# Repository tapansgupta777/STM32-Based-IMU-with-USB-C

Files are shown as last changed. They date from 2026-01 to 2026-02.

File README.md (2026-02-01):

# STM32-Based Inertial Measurement Unit (IMU) Module with USB-C

## 1. Project Overview

> NOTE :
> This project is a result of independent, self-directed study into professional PCB and circuit design. 
> I have implemented an industry-standard design flow modeled after professional methodologies
> . As this is a learning-focused implementation, 
> certain oversights or errors may exist. I highly value constructive feedback, 
> technical suggestions, or design recommendations to further my growth in this field.

This project presents a **custom STM32-based inertial measurement unit (IMU) module** built around the **STM32F411CEU6** microcontroller and the **MPU-6050** six-axis motion sensor. The board is designed as a compact embedded platform for motion sensing, orientation tracking, and IMU data acquisition.

A **USB Type-C interface** is used for both **power delivery and data communication**, allowing IMU data to be transferred directly to a host system while providing a robust and reversible physical connector. The design integrates USB protection circuitry and a regulated power architecture suitable for reliable embedded operation.

The complete schematic and PCB layout were developed in **Altium Designer**, following established industry practices for power integrity, grounding, and multilayer PCB design.

---

## 2. System Workflow

The following diagram illustrates the high-level operational workflow of the STM32-based IMU module, including power delivery, motion sensing, data processing, and host communication.

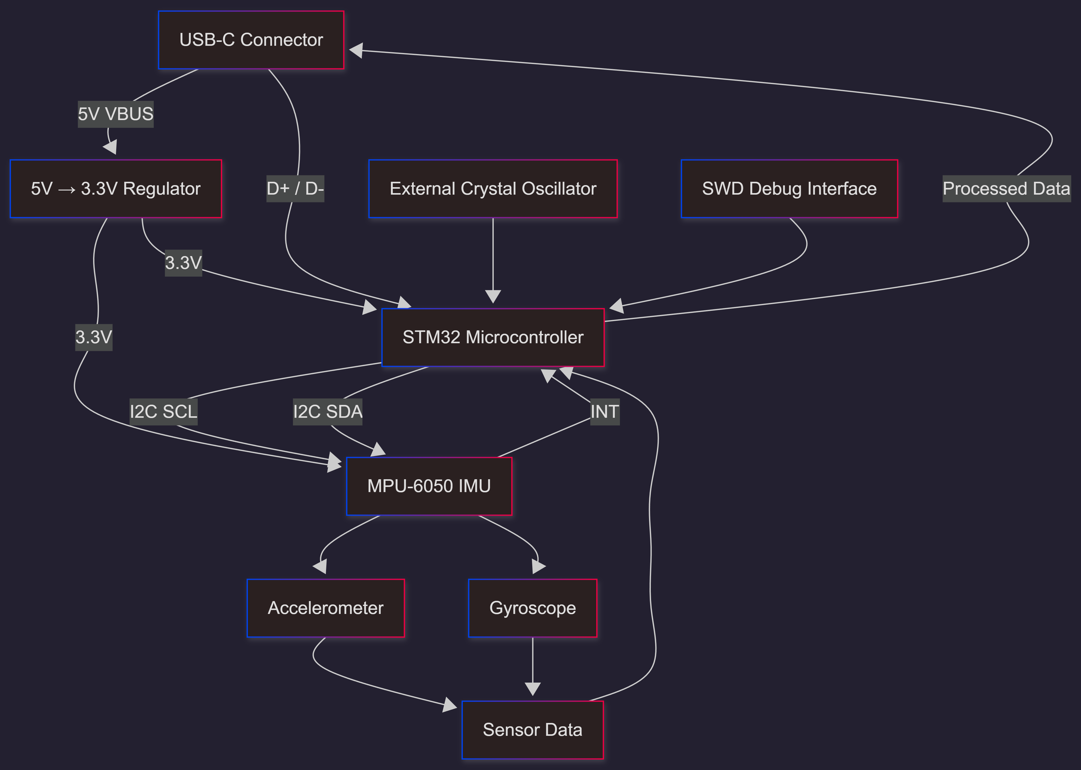
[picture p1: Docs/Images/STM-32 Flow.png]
System Workflow Diagram


---

## 3. System Architecture

At a system level, the module consists of four primary functional blocks:

- USB-C interface for power and USB 2.0 data
- Power regulation subsystem generating a stable 3.3 V rail
- STM32F411 microcontroller for control and processing
- MPU-6050 IMU for motion sensing

The STM32 acts as the central controller, acquiring motion data from the IMU over I²C, processing it in firmware, and transmitting it to an external host via USB.

### Hardware Architecture Summary

| Summary | Schematic |
| --- | --- |
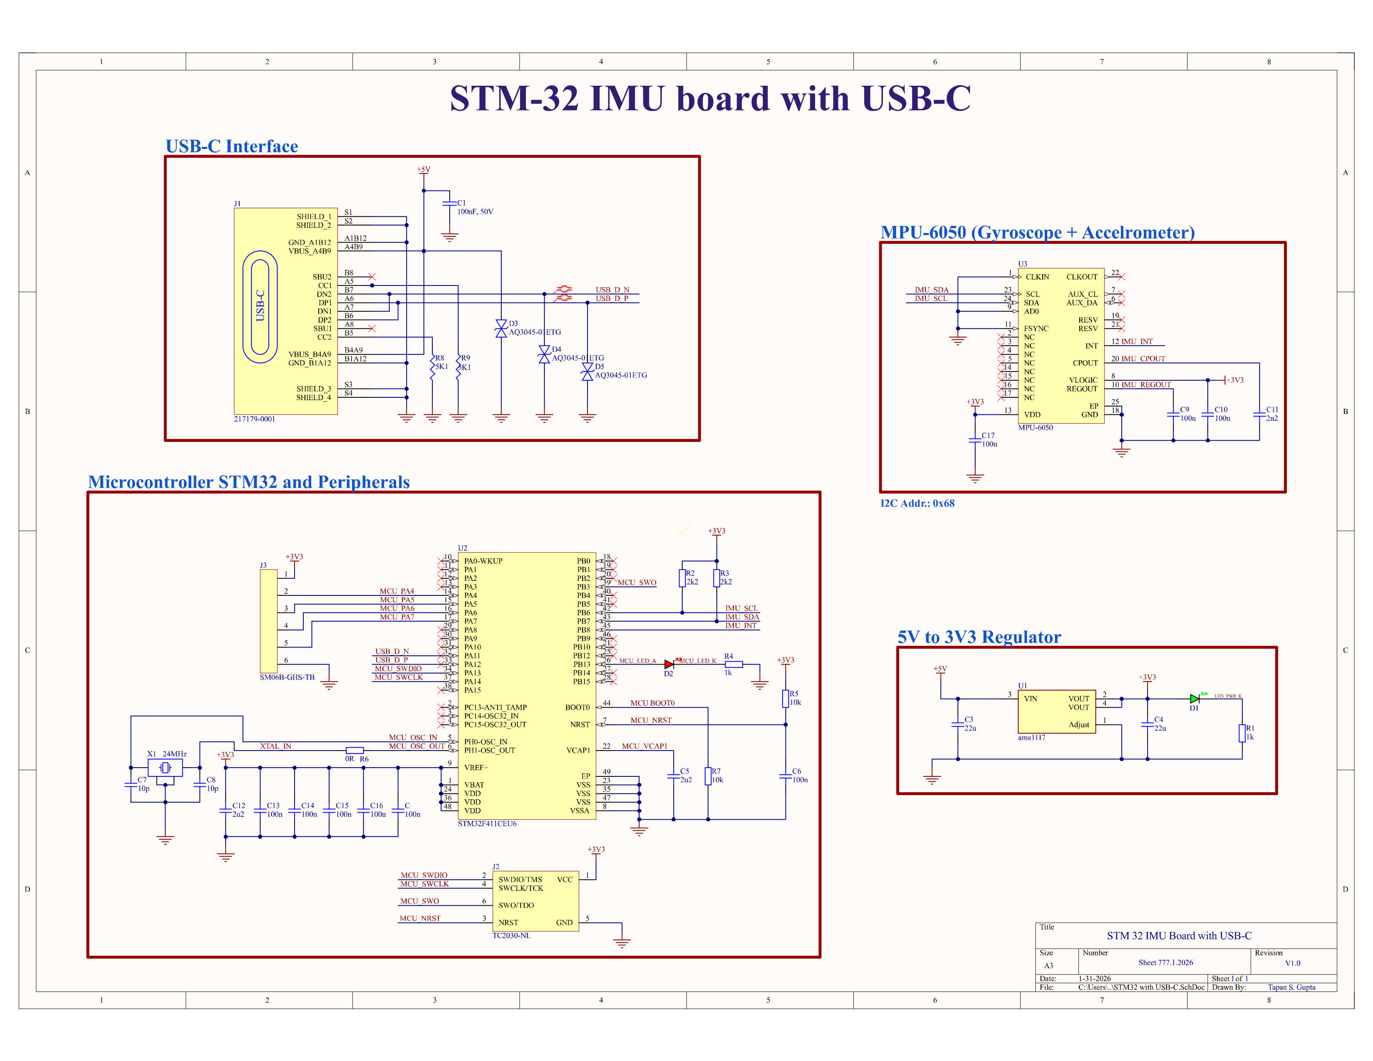
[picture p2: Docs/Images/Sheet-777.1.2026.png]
Design
| • **MCU:** `STM32F411CEU6 with 24MHz external crystal and SWD via Tag-Connect.` <br> • **Sensor:** `MPU-6050 6-axis IMU via I2C (PB8/PB9).` <br> • **USB-C:** `With ESD protection and 5.1kΩ CC pull-downs.` <br> • **Power:** `AMS1117-3.3V LDO converts 5V VBUS to 3.3V.` <br> • **I2C Addr:** `0x68 (AD0 to GND).` <br> • **Interrupts:** `IMU_INT on PB12.` <br> • **Indicators:** `Power LED + Status LED (PB13).` <br> • **Decoupling:** `100nF/2.2µF filter network.` <br> • **Routing:** `USB 90Ω differential impedance.` <br> • **IO Layout:** `Compact 6-pin header.` |  |

---

## 4. Hardware Design

### 4.1 MCU Subsystem

The microcontroller subsystem is based on the **STM32F411CEU6**, an ARM Cortex-M4 device with floating-point support.

Key design aspects include:
- External **24 MHz crystal oscillator** for accurate system timing
- SWD interface for programming and debugging
- Dedicated decoupling capacitors placed close to VDD pins
- Clean ground reference through continuous internal ground planes

The MCU is configured as a USB device and manages sensor communication, data handling, and host interaction.

---

### 4.2 IMU Subsystem

The motion sensing subsystem uses the **MPU-6050**, providing:
- 3-axis accelerometer
- 3-axis gyroscope

Design characteristics:
- Communication via I²C bus
- On-board I²C pull-up resistors
- IMU interrupt pin routed to the STM32 for event-driven data handling
- Placement optimized to reduce noise coupling from power and USB traces

The interrupt line enables efficient motion data acquisition without constant polling.

---

### 4.3 Power & USB-C Subsystem

Power is supplied through a **USB Type-C connector (217179-0001)** configured for USB 2.0 operation.

Key elements:
- 5 V input from USB-C
- **AMS1117 LDO** regulating 5 V down to 3.3 V
- USB ESD protection using **AQ3045-01ETG** diodes
- Common 3.3 V rail shared by MCU and IMU

The USB-C port supports both power input and data transfer, enabling a single-cable interface for development and data logging.

---

## 5. PCB Stackup & Layout

The PCB uses a **4-layer stackup** to improve signal integrity and reduce noise.

- Dedicated internal ground planes provide a low-impedance return path
- Extensive ground stitching vias are used to minimize EMI
- Sensitive IMU signals are routed away from high-speed USB traces

Board dimensions: **36 cm × 36 cm**

<p float="centre">
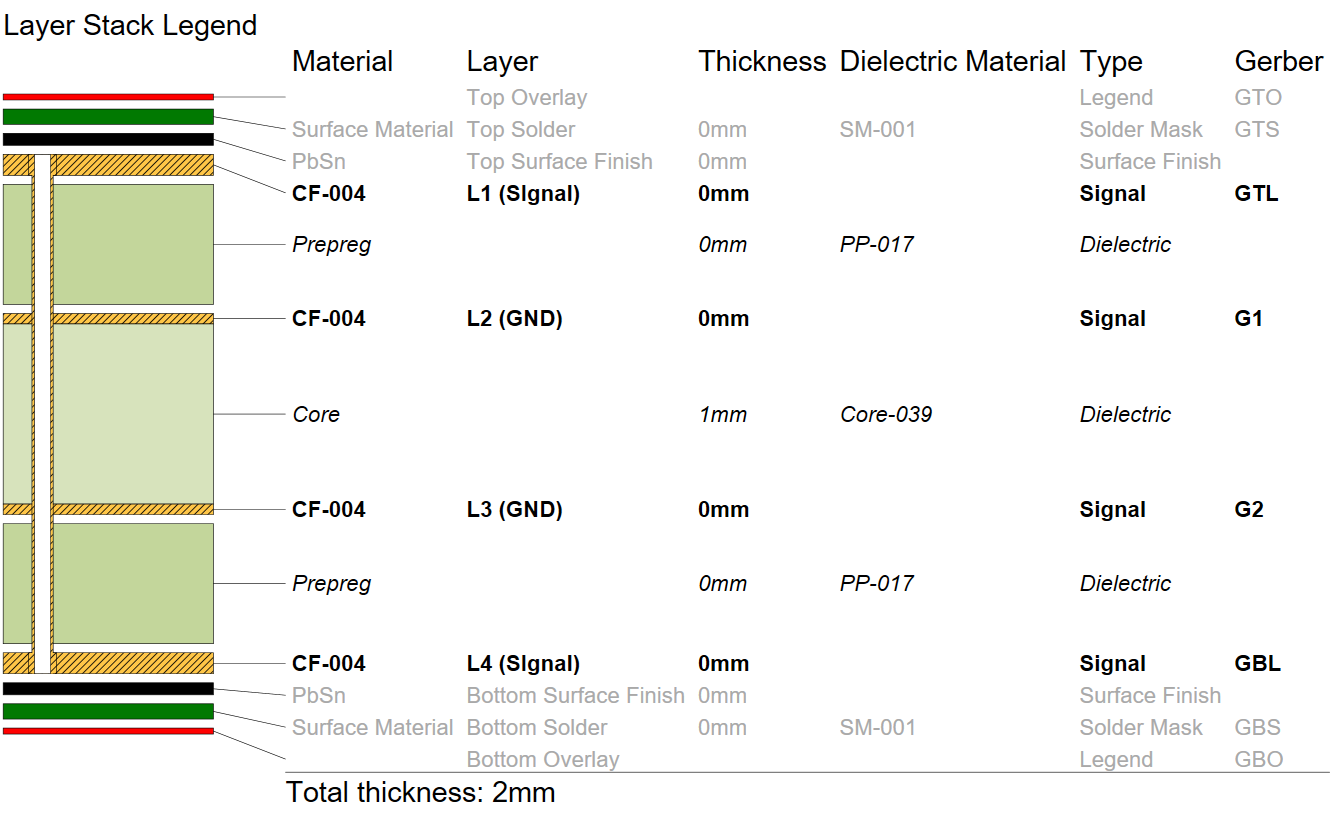
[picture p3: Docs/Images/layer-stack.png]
  
</p>

<p float="left">
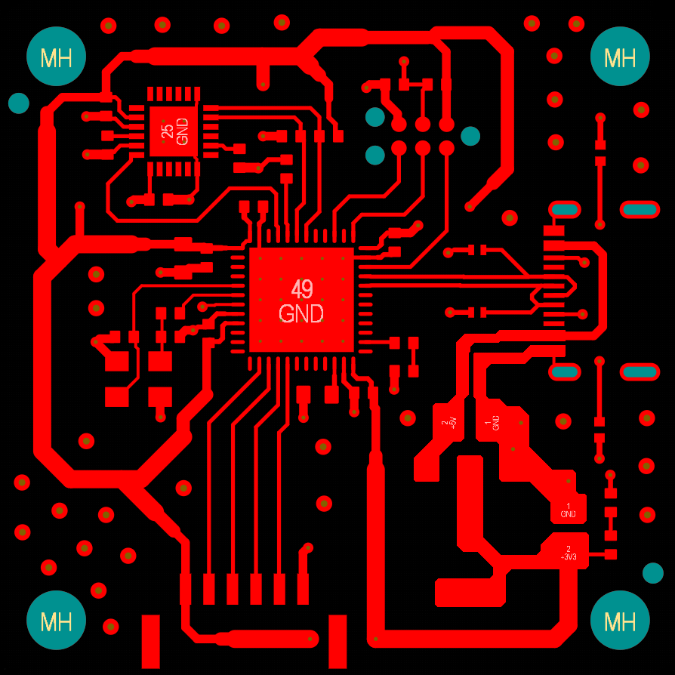
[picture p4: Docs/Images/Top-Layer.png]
  
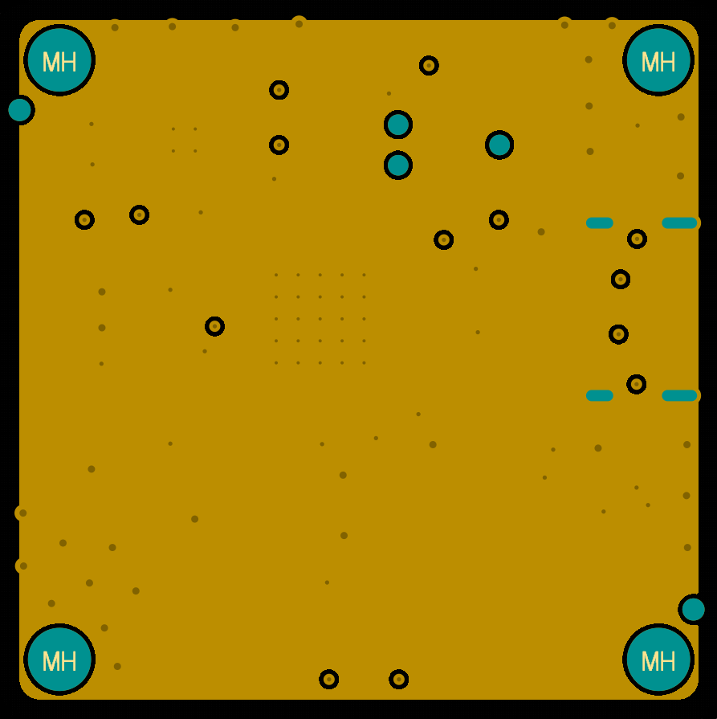
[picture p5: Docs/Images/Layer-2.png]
  
</p>
<p float="left">
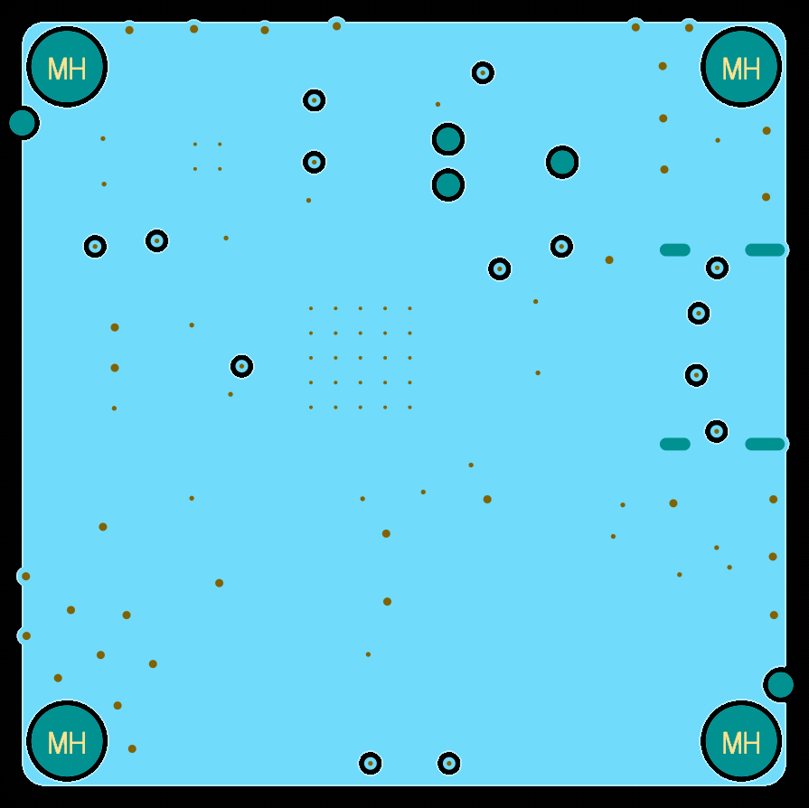
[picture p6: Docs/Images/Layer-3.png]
  
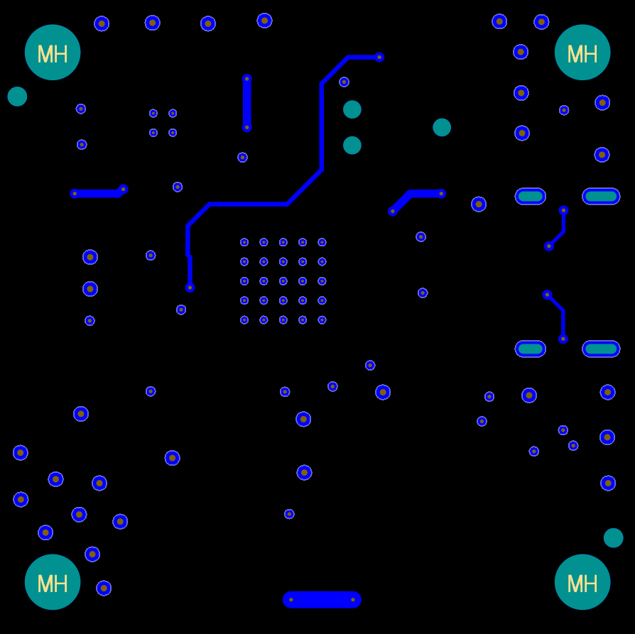
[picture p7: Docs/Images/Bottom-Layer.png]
  
</p>

---

## 6. Firmware Overview

The firmware workflow is centered around **STM32CubeIDE**, which was used to configure:
- MCU pin assignments
- Clock sources
- Peripheral initialization

The firmware is intended to:
- Initialize I²C communication with the IMU
- Handle IMU interrupt events
- Read and process motion data
- Transmit sensor data to a host system over USB

---

## 7. Power Budget

The system operates from a 5 V USB input, regulated to 3.3 V for logic and sensing.

- STM32F411 microcontroller powered from 3.3 V
- MPU-6050 IMU powered from 3.3 V
- AMS1117 LDO selected to support the expected load current

---

## 8. Testing & Validation

Design validation focused on:
- Power rail continuity and voltage regulation
- USB signal routing and ESD protection
- I²C connectivity between MCU and IMU
- Interrupt routing from IMU to MCU

---

## 9. Bill of Materials (BOM)

The following image provides a detailed overview of the major components used in the design, including the microcontroller, IMU, power regulation, USB-C interface, and protection devices.

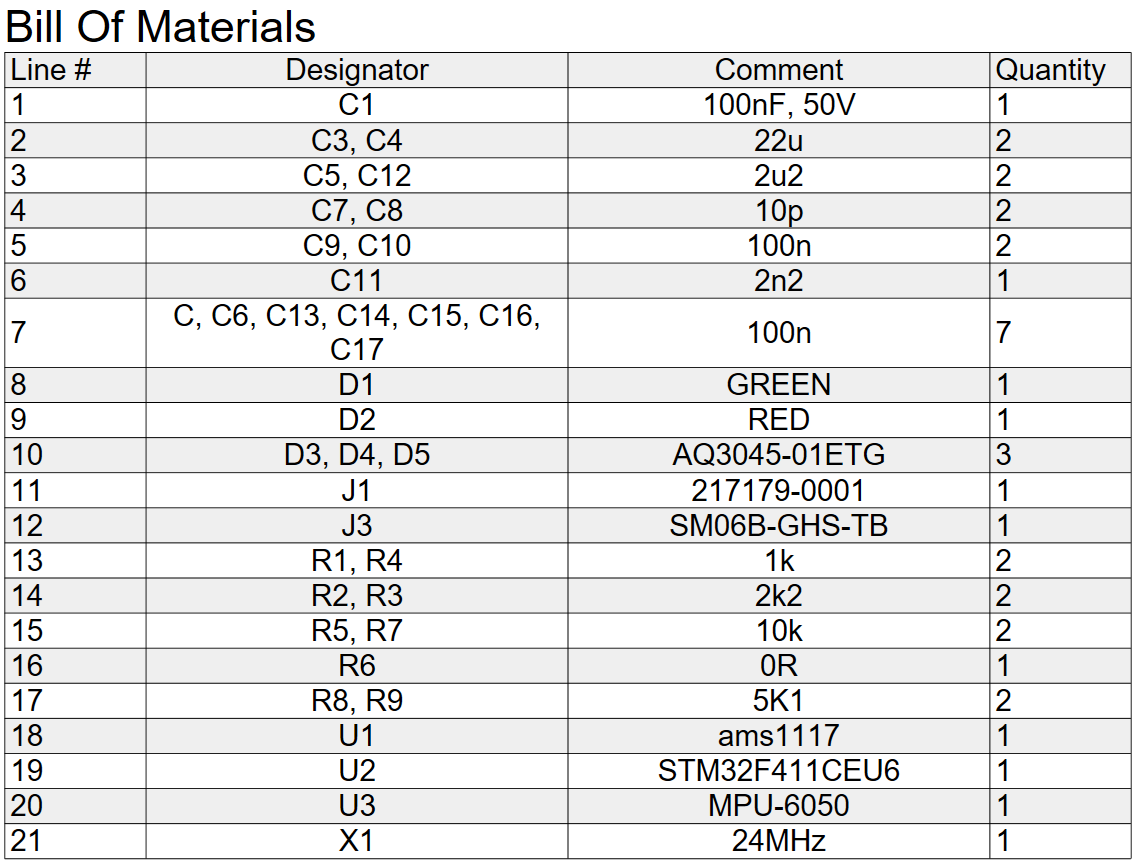
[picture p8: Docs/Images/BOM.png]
Bill of Materials


---

## 10. 3D Model

A complete 3D model of the PCB is available for mechanical reference and enclosure design.

<p float="left">
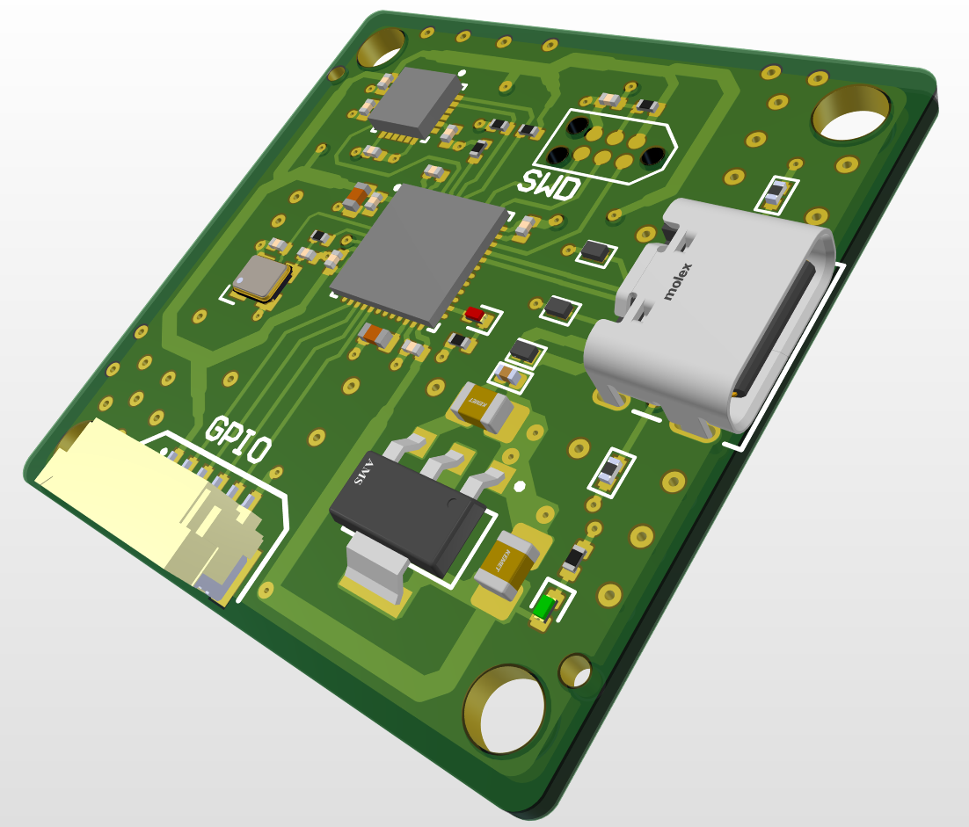
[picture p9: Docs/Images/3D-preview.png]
  
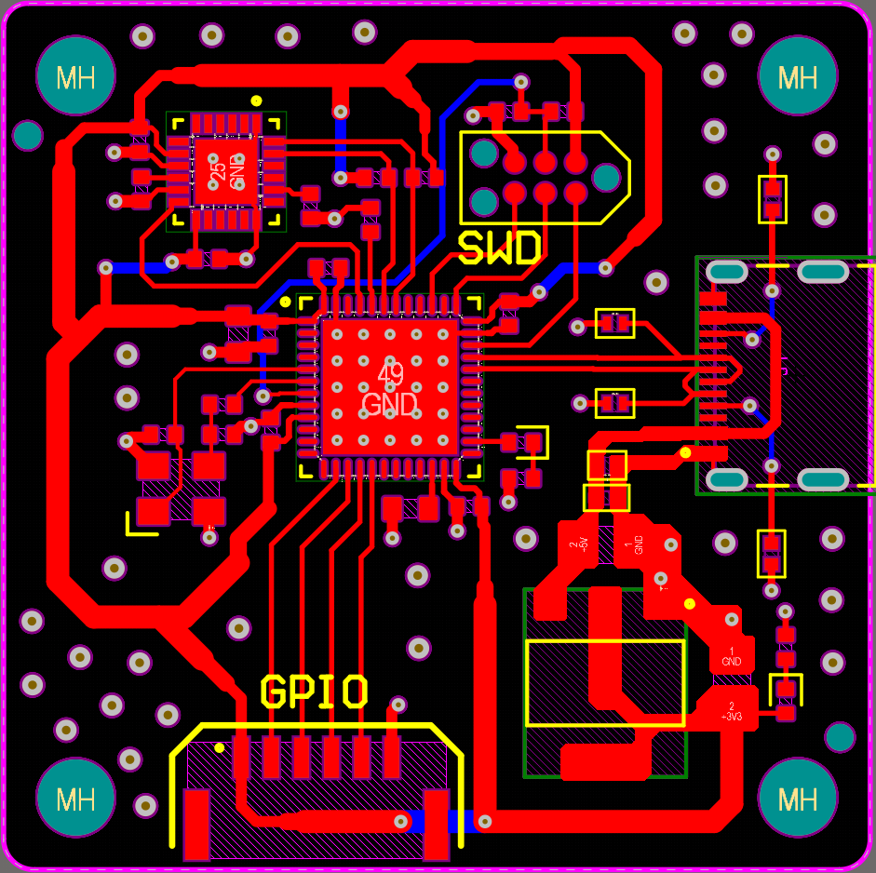
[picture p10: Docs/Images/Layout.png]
  
</p>

Download the 3D model:  
[PCB STEP Model](Docs/Project-Files/stm32-imu-board.step)

---

## 11. License

This project is licensed under the **MIT License**.  
See the [LICENSE](LICENSE) file for details.

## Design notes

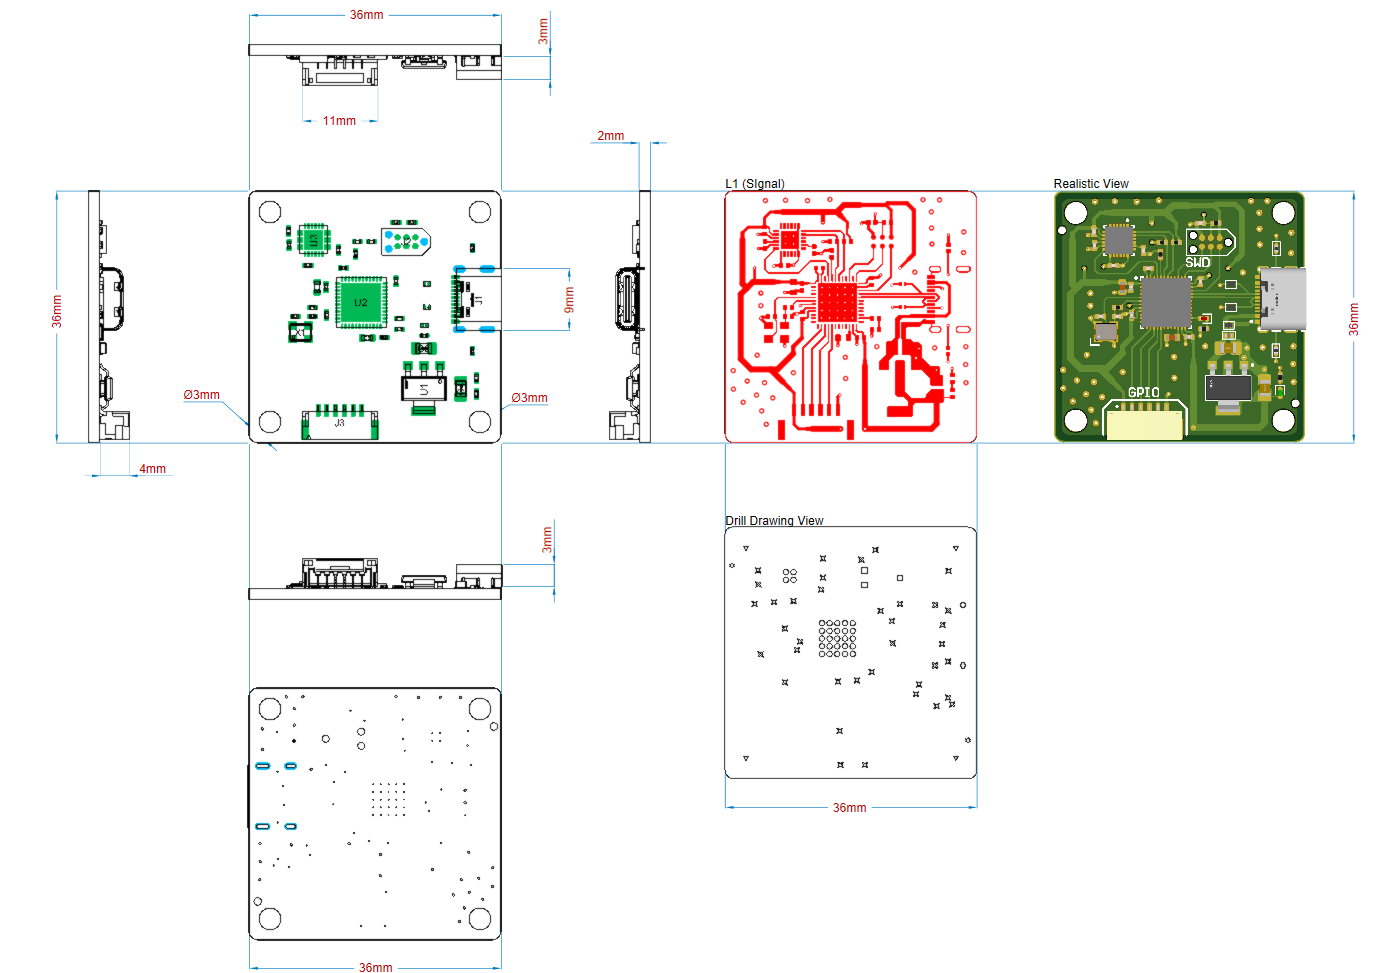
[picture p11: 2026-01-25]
Docs/Images/design.png

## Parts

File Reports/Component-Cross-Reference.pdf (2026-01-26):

Comment | Description | Designator | Footprint | LibRef | Quantity

100n, 100nF, 50V, 22u,
2u2, 10p, 2n2, GREEN,
RED, AQ3045-01ETG,
217179-0001, SM06B-GHS-TB, 1k, 2k2, 10k,
0R, 5K1, ams1117,
STM32F411CEU6, MPU-6050, 24MHz

Capacitor SMD 0402,
CAP CER 0.1UF 50V
X7R 0402, Capacitor
SMD 0805 16V,
Capacitor SMD 0603,
Capacitor SMD 0402
16V, LED 0402 GREEN
SMD, LED 0402 RED
SMD, Bi 30Kv 5V 0.35Pf
Automotve Tvs Sod882/
T&r Rohs Compliant:
Yes, USB Connector,
USB Type C, USB 2.0,
Receptacle, 16 Ways,
Surface Mount,
Through Hole Mount,
Header Connector 6
Position 1.25MM Pitch
SMD Horizontal JST
GH, Resistor SMD
0402, Resistor SMD
0402 0R, Res Thick
Film 0402 5.1K Ohm
1% 0.063W(1/16W)
±100ppm/C Pad SMD
Automotive T/R, 1A
LOW DROPOUT
VOLTAGE REGULATOR,
ARM Cortex-M4 32-bit
MCU+FPU, 512 KB
Flash, 128 KB RAM, 36
I/Os, 48-Pin UFQFPN, -

C, C1, C3, C4, C5, C6,
C7, C8, C9, C10, C11,
C12, C13, C14, C15,
C16, C17, D1, D2, D3,
D4, D5, J1, J3, R1, R2,
R3, R4, R5, R6, R7, R8,
R9, U1, U2, U3, X1

CAP_0402,
CAPC1005X55N,
CAP_0805, CAP_0603,
LED_0402_GREEN,
LED_0402_RED,
SOD882, FP-2171790001-MFG,
SM06B-GHS-TB,
RES_0402,
RESC1005X37N, FPams1117-IPC_C, STM-UFQFPN48_L, IS-QFN-24_V, XTAL_3225

CAP_0402,
CL05B104KB5NNNC,
CAP_0805, CAP_0603,
LED_0402_GREEN,
LED_0402_RED,
AQ3045-01ETG,
217179-0001, SM06B-GHS-TB, RES_0402,
AC0402FR-075K1L,
CMP-209535-000002-1,
CMP-0243-00165-1,
CMP-1753-00002-2,
TSX-3225_24.0000MF15X-AC

37

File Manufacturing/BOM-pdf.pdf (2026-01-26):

Comment | Description | Designator | Footprint | LibRef | Quantity
100nF, 50V | CAP CER 0.1UF 50V X7R 0402 | C1 | CAPC1005X55N | CL05B104KB5NNNC | 1
22u | Capacitor SMD 0805 16V | C3, C4 | CAP_0805 | CAP_0805 | 2
2u2 | Capacitor SMD 0603 | C5, C12 | CAP_0603 | CAP_0603 | 2
10p | Capacitor SMD 0402 16V | C7, C8 | CAP_0402 | CAP_0402 | 2
2n2 | Capacitor SMD 0402 16V | C11 | CAP_0402 | CAP_0402 | 1
100n | Capacitor SMD 0402, Capacitor SMD 0402 16V | C, C6, C9, C10, C13, C14, C15, C16, C17 | CAP_0402 | CAP_0402 | 9
GREEN | LED 0402 GREEN SMD | D1 | LED_0402_GREEN | LED_0402_GREEN | 1
RED | LED 0402 RED SMD | D2 | LED_0402_RED | LED_0402_RED | 1
AQ3045-01ETG | Bi 30Kv 5V 0.35Pf Automotve Tvs Sod882/ T&r Rohs Compliant: Yes | D3, D4, D5 | SOD882 | AQ3045-01ETG | 3
217179-0001 | USB Connector, USB Type C, USB 2.0, Receptacle, 16 Ways, Surface Mount, Through Hole Mount | J1 | FP-2171790001-MFG | 217179-0001 | 1
SM06B-GHS-TB | Header Connector 6 Position 1.25MM Pitch SMD Horizontal JST GH | J3 | SM06B-GHS-TB | SM06B-GHS-TB | 1
1k | Resistor SMD 0402 | R1, R4 | RES_0402 | RES_0402 | 2
2k2 | Resistor SMD 0402 | R2, R3 | RES_0402 | RES_0402 | 2
10k | Resistor SMD 0402 | R5, R7 | RES_0402 | RES_0402 | 2
0R | Resistor SMD 0402 0R | R6 | RES_0402 | RES_0402 | 1
5K1 | Res Thick Film 0402 5.1K Ohm 1% 0.063W(1/16W) ±100ppm/C Pad SMD Automotive T/R | R8, R9 | RESC1005X37N | AC0402FR-075K1L | 2
ams1117 | 1A LOW DROPOUT VOLTAGE REGULATOR | U1 | FP-ams1117-IPC_C | CMP-209535-000002-1 | 1
STM32F411CEU6 | ARM Cortex-M4 32-bit MCU+FPU, 512 KB Flash, 128 KB RAM, 36 I/Os, 48-Pin UFQFPN, -40 to 85 degC, Tray | U2 | STM-UFQFPN48_L | CMP-0243-00165-1 | 1
MPU-6050 | 3-Axis Gyroscope, Accelerometer and a Digital Motion Processor(TM) (DMP), 2.375 to 3.46 V, -40 to 85 degC, 24-Pin QFN, RoHS, Tape and Reel | U3 | IS-QFN-24_V | CMP-1753-00002-2 | 1
24MHz | Crystal SMD 24MHz 10PPM 7pF 3225 | X1 | XTAL_3225 | TSX-3225_24.0000MF15X-AC | 1

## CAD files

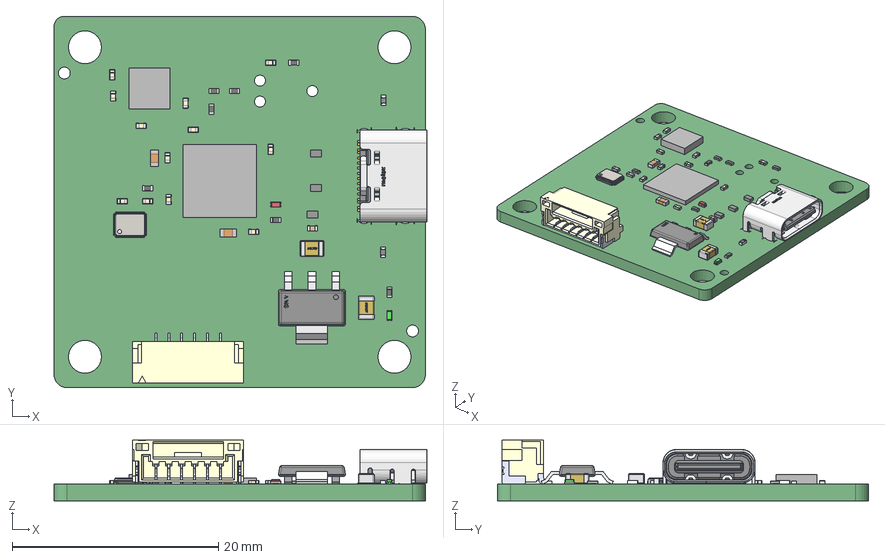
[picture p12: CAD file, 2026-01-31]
Docs/Project-Files/stm32-imu-board.step
36.2 x 36.0 x 5.88 mm
Notch
Molex
AQ3045-01ETG x 3
CL05A105KL5NRNC
Y3225
Extruded x 2
IC_Advanced_Monolithic_Systems_ams1117_eec
R0402 x 7
SM06B-GHS-TB
LED0402-Red
LED0402-Green
C0402 x 12
C0603 x 2

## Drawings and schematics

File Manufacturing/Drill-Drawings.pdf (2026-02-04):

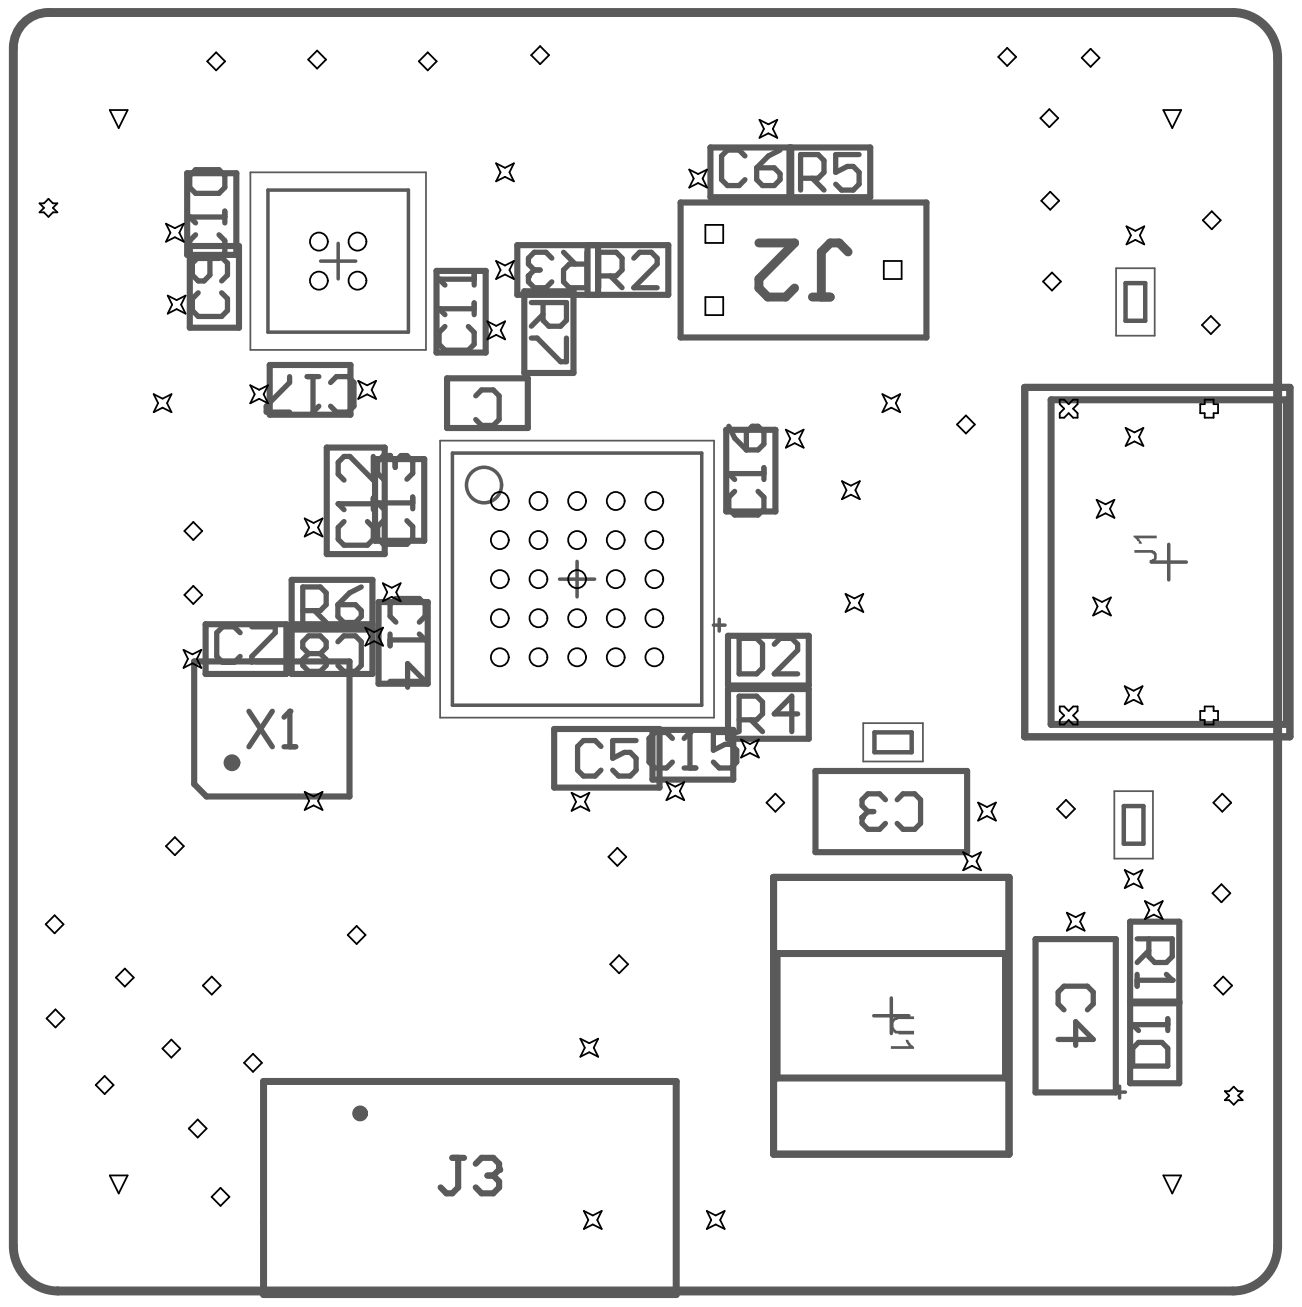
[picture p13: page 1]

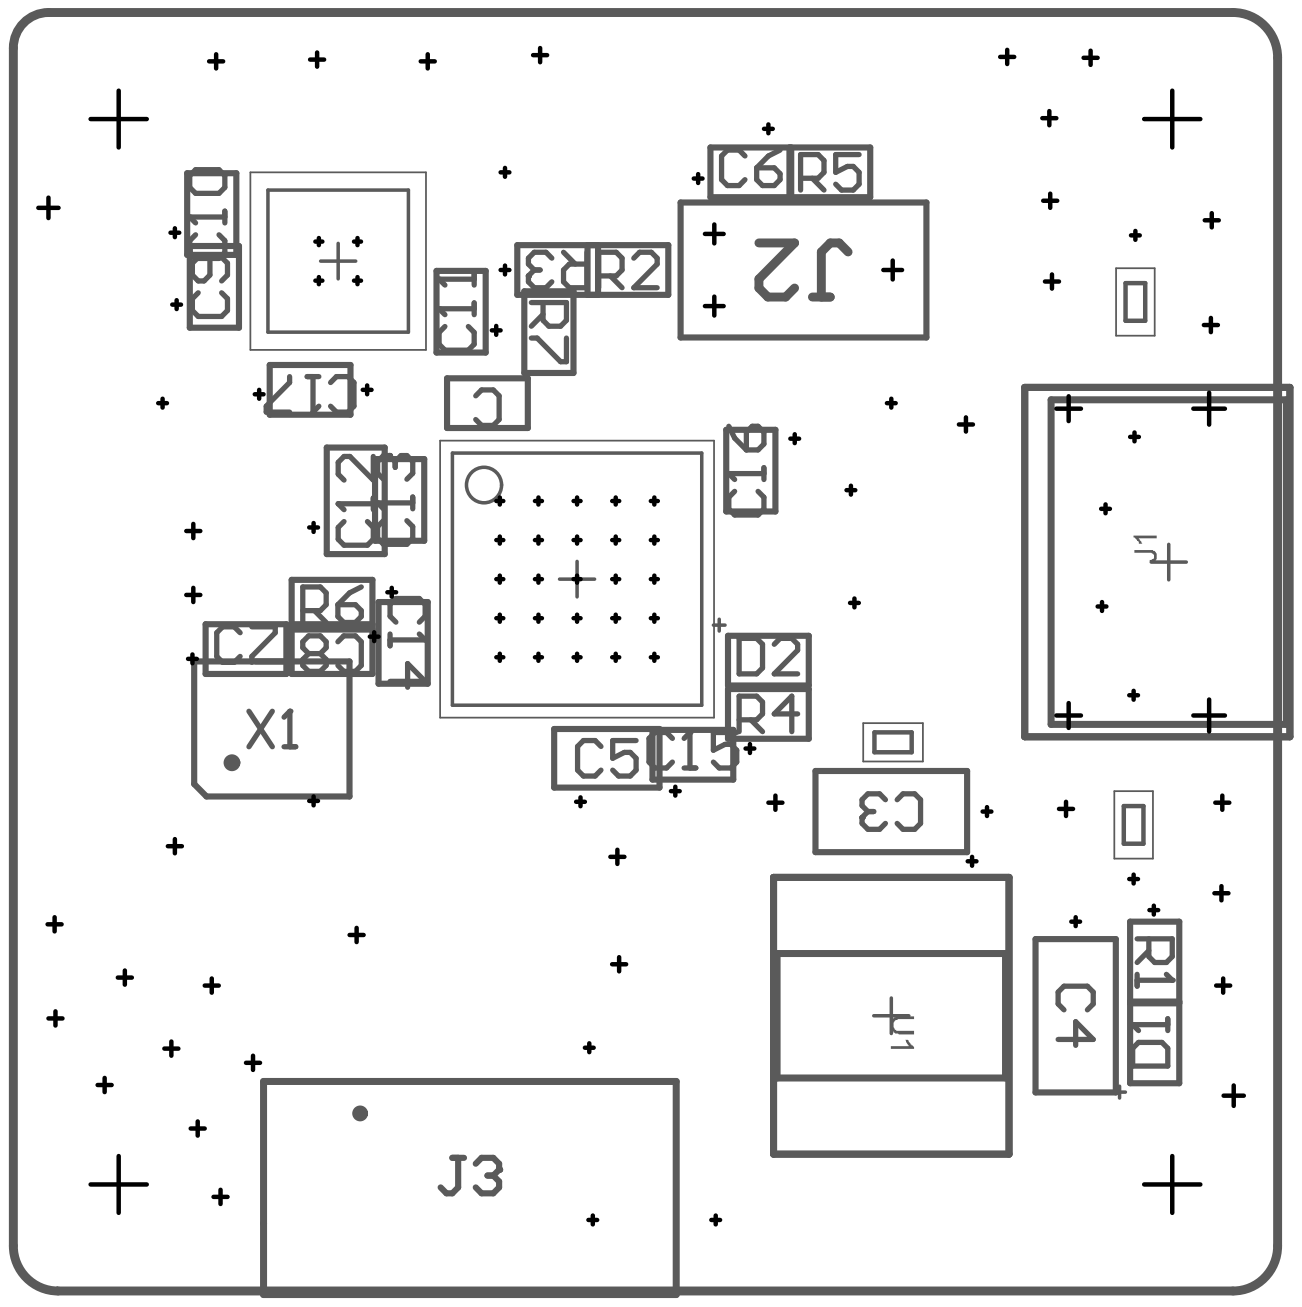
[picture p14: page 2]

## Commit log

2026-01-21 Rename STM32 Motion Data Flow-2026-01-21-170634.png to STM32 Data Flow.png
2026-01-21 Rename STM32 Motion Data Flow-2026-01-21-174023.png to STM32 Motion Data Flowg
2026-01-26 Revise PCB layout and power budget details
    Updated PCB layout and power budget sections in README.
2026-01-31 Revise schematic explanatory text
    Updated explanatory text for the schematic.
